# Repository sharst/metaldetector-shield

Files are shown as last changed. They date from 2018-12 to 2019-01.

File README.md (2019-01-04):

# metaldetector-shield
Hardware and Software for a custom built metaldetector + pressure sensing shield.
This shield was used in a robotics project for contactless navigation (see https://www.youtube.com/watch?v=rSrG_VnvrPk). 
The hardware and software were jointly developed by Simon Harst and Stefan Brüwer.

## It features:
* connection of up to 8 coils which emit and receive electromagnetical impulses
* connection of up to 8 pressure sensors to detect air pulses
* 24V connection with on-board conversion to 5V for the microcontroller
* on-board CAN-Controller to connect the board to a CAN-bus
* chaining possibility to connect two or more boards together for infinite extension
* a ROS example to use it in your robotics application: [www.github.com/sharst/metaldetector-ros](https://github.com/sharst/metaldetector-ros)

## What you can do with it:
* Contactlessly detect metal objects in the vicinity (distance depends on the coil and object used)
* build a rig of 8, 16 or more coils by chaining several boards together
* detect changes in air pressure (in our case upon collision inside an inflateable bumper)
* send all the information on a CAN or serial bus

The board and all accompanying software is fully open source, so you can get involved, too!

## Hardware setup
### How does this work?
The heart of this shield is an arduino microcontroller, which rapidly triggers 8 rigs of transistors connected to coils. From the impulse of current, the coils generate an electromagnetical impulse. In case there is metal in front of the coil, it will reflect part of the impulse which in turn can be sensed by the coil. The weaker echo of the impulse is again converted to current in the coil, which is measured by an ADC on the board. If you want to see a typical response as measured by the ADC, check out the coil response gif below (--> Configuration files). The board sums up the response. This sum can be used to infer whether a metal object is present and how far away it is.

In addition, the shield can measure impact in terms of air pressure. To do that it constantly measures a rolling average of up to 8 air pressure sensors independently. In case it measures a spike of air pressure above a threshold, it emits a custom message.

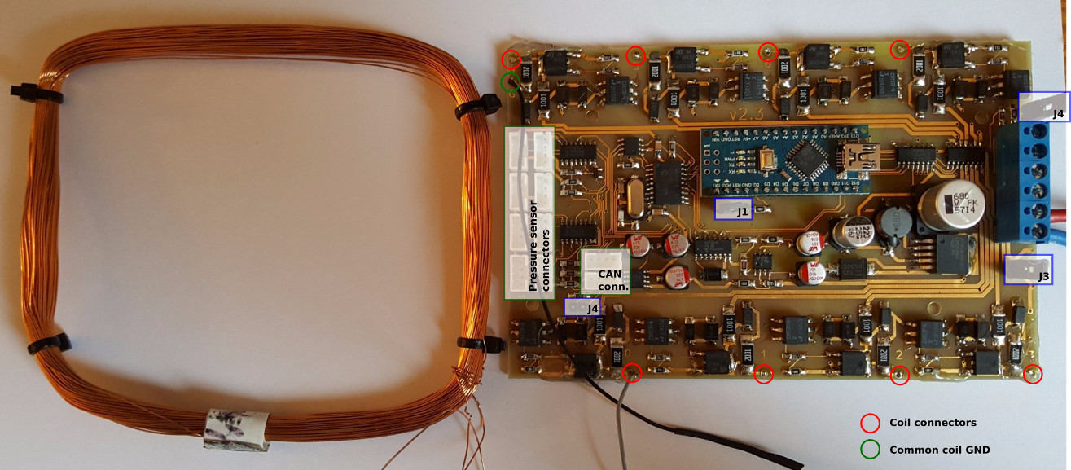
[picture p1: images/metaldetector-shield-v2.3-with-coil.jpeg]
The metaldetector shield


This is what needs to be done to get one board running (no chaining):
* Solder at least one sensing coil to the COIL_GND and COIL_0 inputs (for more information, check out --> "A note on the coils"
* (Optionally) connect one BMP180-pressure sensor to one of the pressure inputs
* Connect the arduino on the board to your PC and flash the current firmware
* Set jumper J1 to set the board to MASTER mode
* Set jumper J2 to disable chaining
* In case you do not have a coil/capacitor installed at the 24V input, set jumper J3 to bridge the coil connector
* Connect 24V to one of the 24V ports
* The values of the coils are being output on the serial port now (115200baud)

### To enable chaining
Chaining allows you to connect two boards together. The impulses of the coils will influence one another. Therefore you should not operate two coils close together if you want accurate results. The metaldetector board already takes care that up to 8 coils are fired independently in a row and do not influence each other. If you need more than 8 coils, you can use chaining. Chaining uses an additional signal line between two boards, and the boards will take care to always fire their coils alternatingly.
* Remove jumper J2 to enable chaining
* Set jumper J1 on one board to make it the chaining MASTER. Remove the jumper on all other boards to make them slaves
* You can directly chain the 24V power source as well by connecting the secondary 24V-port to the next board
* Connect to signal wires between the boards. The first one should go from output (>) on board 1 to input (<) on board 2. The second one goes from input (<) on board 1 to output (>) on board 2.
* If you want to connect more than two boards together, connect them in a circle, always taking care that the output goes to the input of the next board, and the input is connected to the output of the previous board.
* If you are using the CAN bus, make sure that the boards are using unique CAN addresses (set them in metaldetector-shield.ino --> TX_CAN_ID and RX_CAN_ID)

### How to produce the boards
* We always ordered our boards at PCB-Pool (in Germany). They accept the kicad-files given in the hardware folder directly as input. 
* You can order the entire BOM on farnell, including the wire for the coils. Check out the BOM in the hardware folder.

### A word on the coils
The coils are key when it comes to which objects can be detected. Here's a few notes:
* The larger the coil diameter, the less focused the impulse will be. In general you get a weaker response with larger coils, but also you cover less area
* We tested both with round and rectangular coils, both worked great.
* The more impedance, the less current flow you will get at the fixed 24V, which means less stronger impulses and responses. But it also means less power consumption.
* The more windings the coil has, the stronger the impulse. But also you will naturally get higher impedance with more windings.
* you will have to experiment to find the best tradeoff for your application. In our case it was a coil from 0.4mm wire with 150 windings equalling to ~11 Ohm.

### A note on the pressure sensors
* We ordered the BMP180 sensors on ebay. Note that there are several versions. The boards we used are 1cm x 1.2cm in size. We hand-crimped the cables to connect them via the JST-plugs.
* If you want to use pressure sensors in an outdoor environment, water resistance is key. We used two cable glands connected together to create an air- and water-tight case. We connected an air tube from the one side which guided the air impulse from the bumper cushion into the case (blue arrow). On the other end we connected the air pressure sensor (red arrow). [See image here.](https://github.com/sharst/metaldetector-shield/blob/master/images/air_pressure_connector.jpg).
* For extra water resistance, it is possible to put the pressure sensor into a ballon before inserting it into the cable gland. [See image here.](https://github.com/sharst/metaldetector-shield/blob/master/images/air_pressure_connector_balloon.jpeg)

## Software setup
We've tried to make the software setup as easy as possible for you. Therefore, all the software needed is bundled in this repository, either directly or by submodules.

### To get the arduino running
```
# Go anywhere where you want to check out this repo
cd ~
git clone https://github.com/sharst/metaldetector-shield
cd metaldetector-shield
# Get all the contained submodules
git submodule init 
git submodule update
# The repository contains an arduino folder. This is basically an arduino sketchbook setup and ready to go. First backup your current one:
mv ~/sketchbook ~/sketchbook_bckp
# Now link the one from the repository with a symbolic link. This means you can still use and manage the repository in the original location, but arduino will find your files.
ln -s ~/metaldetector-shield/arduino ~/sketchbook
```
* Open the arduino IDE (tested with v 1.6.9)
* Select Tools --> Board --> Arduino Nano
* Tools --> Programmer --> AVR ISP
* File --> Open --> ~/sketchbook/arduino/metaldetector_shield.ino
* Upload
* Open Serial Console, set it to 115200 baud, watch the output.

### Overview of the software
./arduino: Contains all the software relevant to the arduino (i.e. the firmware and all libraries)
./PythonLivePlotting: A library to do dynamical plots and updates of figures

#### Configuration files
board_v23.h : Contains mostly pin settings (hardwired on the board, don't change them!). You can also set some identifiers on where pressure and heartbeat signals get send on the CAN-BUS, and the identifier to switch coils.  
metaldetector-shield.ino: The main sketch for upload. Contains some interesting settings:
  * TX_CAN_ID: The CAN ID used for writing messages on the bus. If you are using several boards on the same bus, make sure this is unique for each board.
  * RX_CAN_ID: The ID that this board listens on for messages on the bus. You can dynamically switch some functionalities on the board by sending messages. Make sure this ID is unique for this board.
  * DEBUG: Whether or not to output information on the serial bus.
  * COMM_TIMEOUT: How many ms to wait for a signal from the slave board in chaining mode
  * DEBUG_RAW_ADC_COIL: Only works when DEBUG==true. This will output the raw measurements of the given coil as sampled by the ADC. Run python plot_raw_coil.py to visualize these values. This is a sample output where we approach a metal object to the coil:
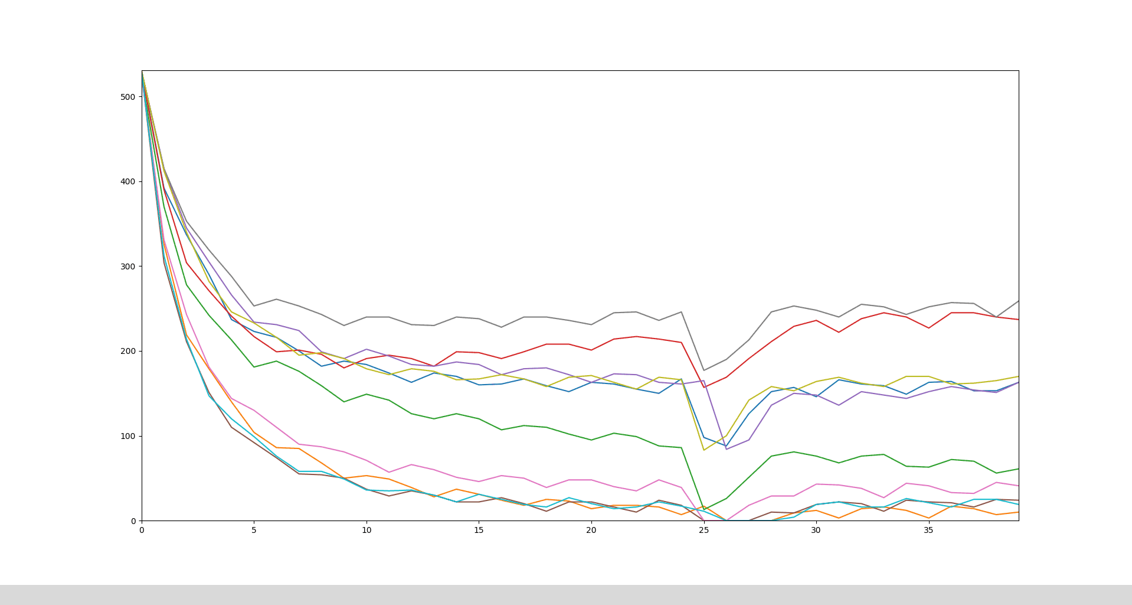
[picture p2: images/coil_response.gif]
Raw output of ADC values

  * DEBUG_RAW_PRESSURE: Only works when DEBUG==true. This will output the raw measurements of the given pressure sensor. Run python plot_raw_pressure.py to visualize these values. This is a sample output where we register several bumper hits on the given pressure sensor. In red are detected collisions.
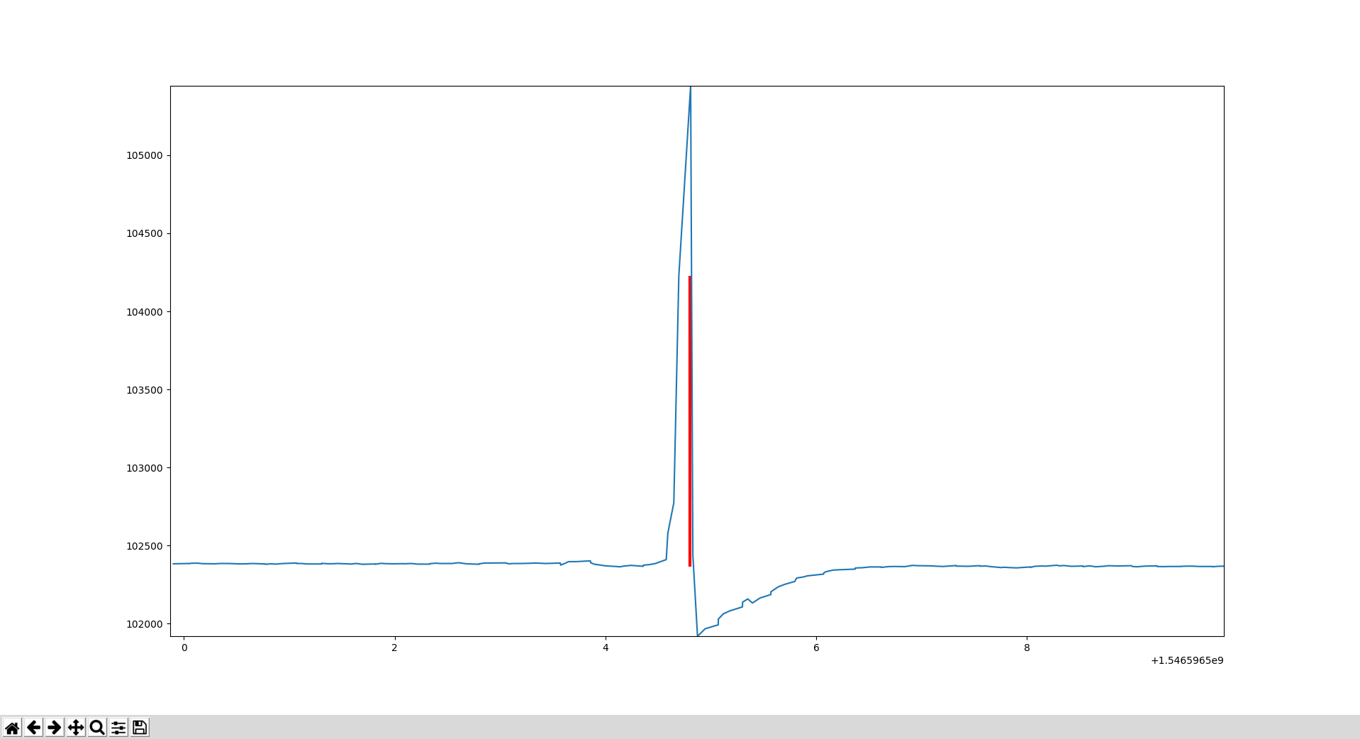
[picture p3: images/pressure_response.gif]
Raw output of pressure values
  

#### Typical operation mode
Check out the loop-function in the main sketch. A loop consists of the following steps:
* If coils are enabled, trigger each coil once and read out the results
* we want to average over several measurements. coil.data_ready() goes to True as soon as we have collected this amount of measurements
* In case some coil data is ready we will output it on the serial bus as a four-byte message, which will be in the format ```[40 (COIL_REGISTER set in board_v23.h), [0-7] (coil_index), highbyte(value), lowbyte(value)]```
* The communication state is toggled so the next board can start measuring
* We now sample the pressure sensors. If one of them transitions a threshold value, we encode this information bitwise. For instance, if pressure sensors 2 and 4 have surpassed the threshold value since the last call, get_bumper_transitions will output 0b00010100 (the second and fourth bit are True).
* We now send out the string "BUMPER" on the serial bus. On the CAN-bus we will send the bitcoded value, this time in the format ```[25 (PRESSURE_REGISTER set in board_v23.h), 0, highbyte(bitcode), lowbyte(bitcode)]```.
* We send out a heartbeat message on the CAN bus. This message contains the information on which ports some pressure sensors are connected and whether the metal sensing functionality is currently switched on. Which ports are currently connected to pressure sensors is again encoded bitwise, i.e. 0b10001001 means that there are sensors connected on the first, fourth and eigth connector on the board. A heartbeat message has the format ```[30 (HEARTBEAT_REGISTER set in board_v23.h), bitwise encoding of connected sensors, (1 or 0 whether coils are enabled)]```

#### Getting the CAN bus running
* In order to interface with a CAN bus from a computer, you typically need a CAN to USB converter. We had some eccellent results with the [USBtin](https://www.fischl.de/usbtin/). It is open source, has a superb interface, a loving maintainer and can be ordered readily assembled.
* In order to connect it, just connect the HIGH, LOW and GND (marked as "T" on the USBtin) lines between the two boards. 
* If you want to connect more metaldetector boards, there are two CAN connectors on each one: One coming in, one going out.
* In addition, you need one termination resistor somewhere on the bus, typically on the last element of the bus chain. If this last element is a metaldetector board, you can simply set jumper J4 to enable the termination resistor.
* Connect the USBTin to your computer, open the interface and set it to 500kbps and see the messages from the board coming in. 
* There is also a ROS driver available which directly interfaces the metaldetector-board to ROS messages [www.github.com/sharst/metaldetector-ros](www.github.com/sharst/metaldetector-ros)

## Summary: Information flow from the metaldetector-shield
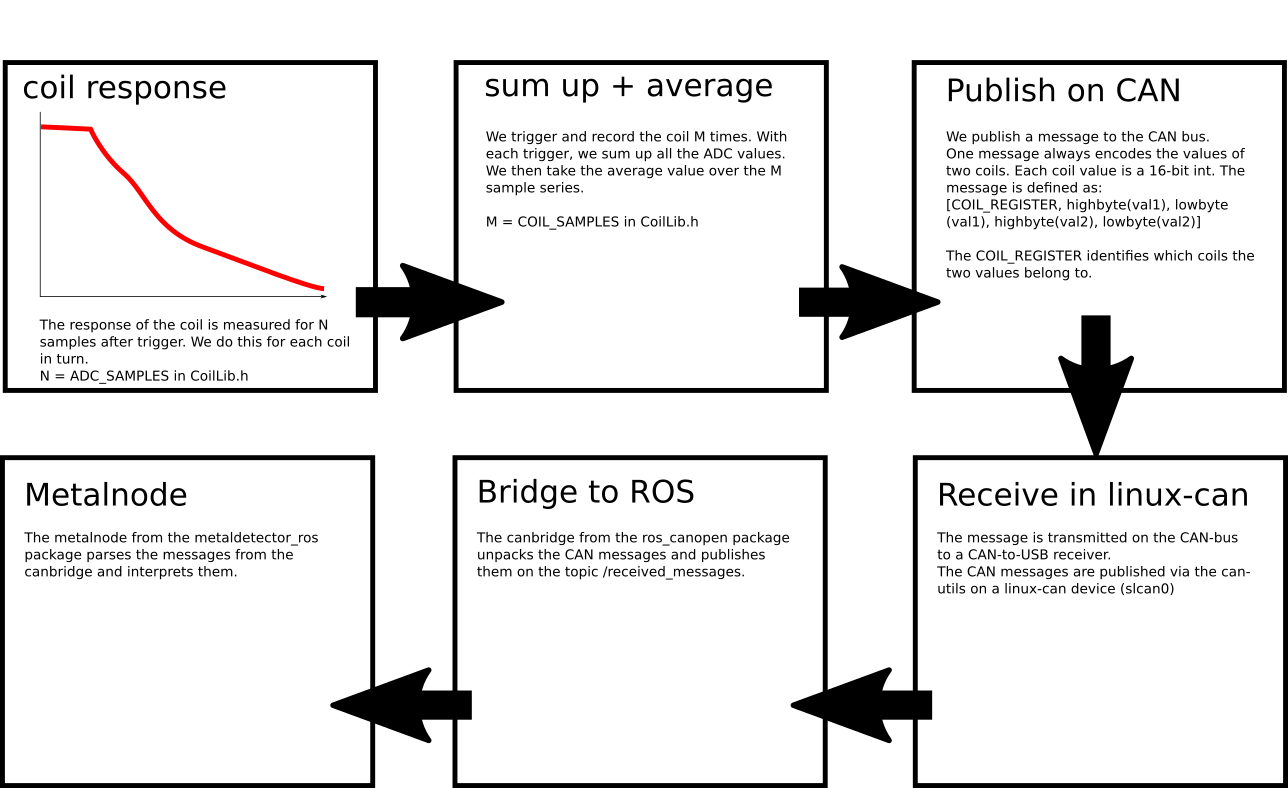
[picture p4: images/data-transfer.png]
Information flow from the metaldetector-shield


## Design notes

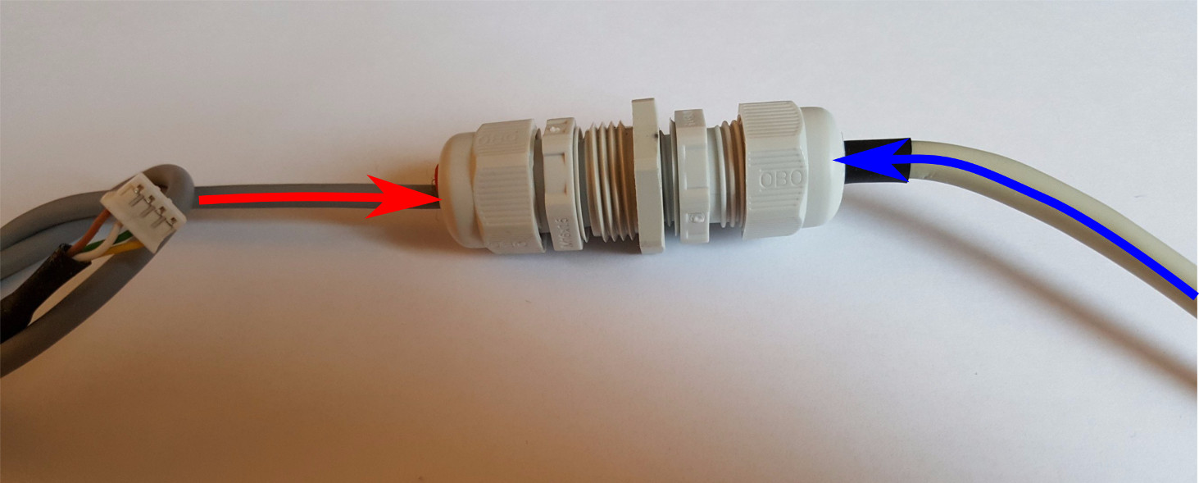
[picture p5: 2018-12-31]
images/air_pressure_connector.jpg

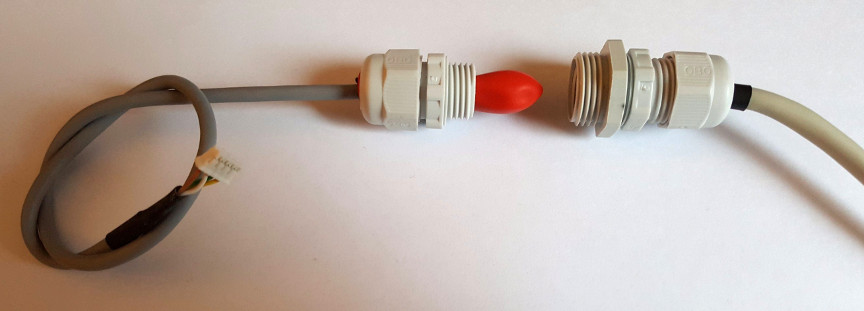
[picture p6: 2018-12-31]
images/air_pressure_connector_balloon.jpeg

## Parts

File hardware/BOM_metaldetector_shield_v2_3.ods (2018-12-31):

BOM Metaldetector Shield v2.3
 |  | SMD
Name | Value | Quantity | Farnell # | Price | Total Price
AMP1 | LF356N | 1 | 9486992 | 0.74 | 0.74
C1, C11, C12 | 47uF | 3 | 2466299 | 0.237 | 0.711
C2 | 16MHz | 1 | 1667017 | 0.357 | 0.357
C3, C4 | 27pF | 2 | 1650899 | 0.109 | 0.218
C5, C6 | 100nF | 2 | 1856626RL | 0.0158 | 0.0316
C7 | 680uF / 50V | 1 | 2326375 | 1.55 | 1.55
C8, C9 | 100uF | 2 | 2466283 | 0.138 | 0.276
C10 | 220uF / 25V | 1 | 2068666 | 0.353 | 0.353 | alternativ 100uF: 1135108
D1, D6, D9, D12, D15, D18, D21, D24, D27, D30, D33 | Schottky 1A / 20V | 9 | 1861424 | 0.0777 | 0.6993
D3 | 1n5824 | 1 | 1843766 | 1.09 | 1.09
D4, D7, D10, D13, D16, D19, D22, D25, D28, D31 | TVS 400V | 8 | 1835131 | 0.673 | 5.384
D5, D8, D11, D14, D17, D20, D23, D26, D29, D32 | TVS 5V | 8 | 1899459 | 0.348 | 2.784
IC1 | 74HC4052 | 2 | 1201328 | 0.361 | 0.722
IC2 | MCP2515 | 1 | 1292239 | 1.86 | 1.86
IC3 | MCP2551 | 1 | 9758569 | 1.06 | 1.06
L1 | 68uH | 1 | 1828056 | 0.414 | 0.414 | alternativ 100uH: 2329044
MCP1 | MCP3008 | 1 | 1292241 | 2.25 | 2.25
P5 | 220 Ohm | 1 | 2447486RL | 0.0042 | 0.0042
Q1-Q10 | Mosfet | 8 | 2344093 | 3.55 | 28.4
R1, R2, R3, R9 | 10k | 4 | 2073878 | 0.0116 | 0.0464
R4, R7, R8 | 100 Ohm | 1 | 1632521 | 0.006 | 0.006
R5 | 560 Ohm | 3 | 1632593 | 0.006 | 0.018
R6 | 560k | 1 | 2145676 | 0.01 | 0.01
R10 | 350 Ohm | 1 | 2142160 | 0.024 | 0.024
R11, R15, R19, R23, R27, R31, R35, R39, R43, R47 | 2k Planar | 8 | 1887796 | 0.857 | 6.856
R12, R16, R20, R24, R28, R32, R36, R40, R44, R48 | 1k / 1W | 8 | 1470042 | 0.16 | 1.28
r14, r18, r22, r26, r30, r34, r38, r42, r46, r50 | 220 Ohm | 8 | 2447486RL | 0.0042 | 0.0336
U1 | ICL7660 | 1 | 9663703 | 1.1 | 1.1
U2 | LM2596-T5.0 | 1 | 1469195 | 4.54 | 4.54
U3, U4, U5, U6 | HEF4051 | 4 | 1201291 | 0.254 | 1.016
U7-U16 | CNY17F OPTO | 8 | 1683186 | 0.57 | 4.56
Arduino Nano | NANO | 1 |  |  | 0
P5, P19, P18 |  | 3 | 2007995 | 0.313 | 0.939
JP1, JP2, JP3, JP4 | 2Pin-Header | 2 | 1248140 | 0.054 | 0.108
JP1, JP2, JP3, JP4 | Jumper 2Pos | 2 | 1908384 | 0.073 | 0.146
J2, P25, P2, P3, P4, P6, P7, P8, P9, P10 | JSP PH 4Pos | 10 | 9492437 | 0.144 | 1.44
R28, R51 | 1k | 10 | DNO | 0 | 0
P5, P18, P19 | Reihenklemmen RM5 | 3 | 2396252 | 0.243 | 0.729
Optional: |  |  |  |  | 67.6541
-- | Drossel |  | 1929754 | 2.9
-- | ELKO 4700uF |  | 1973498 | 2.96
 | Flachsteckeranschluss |  | Reichelt FS-P 2,8

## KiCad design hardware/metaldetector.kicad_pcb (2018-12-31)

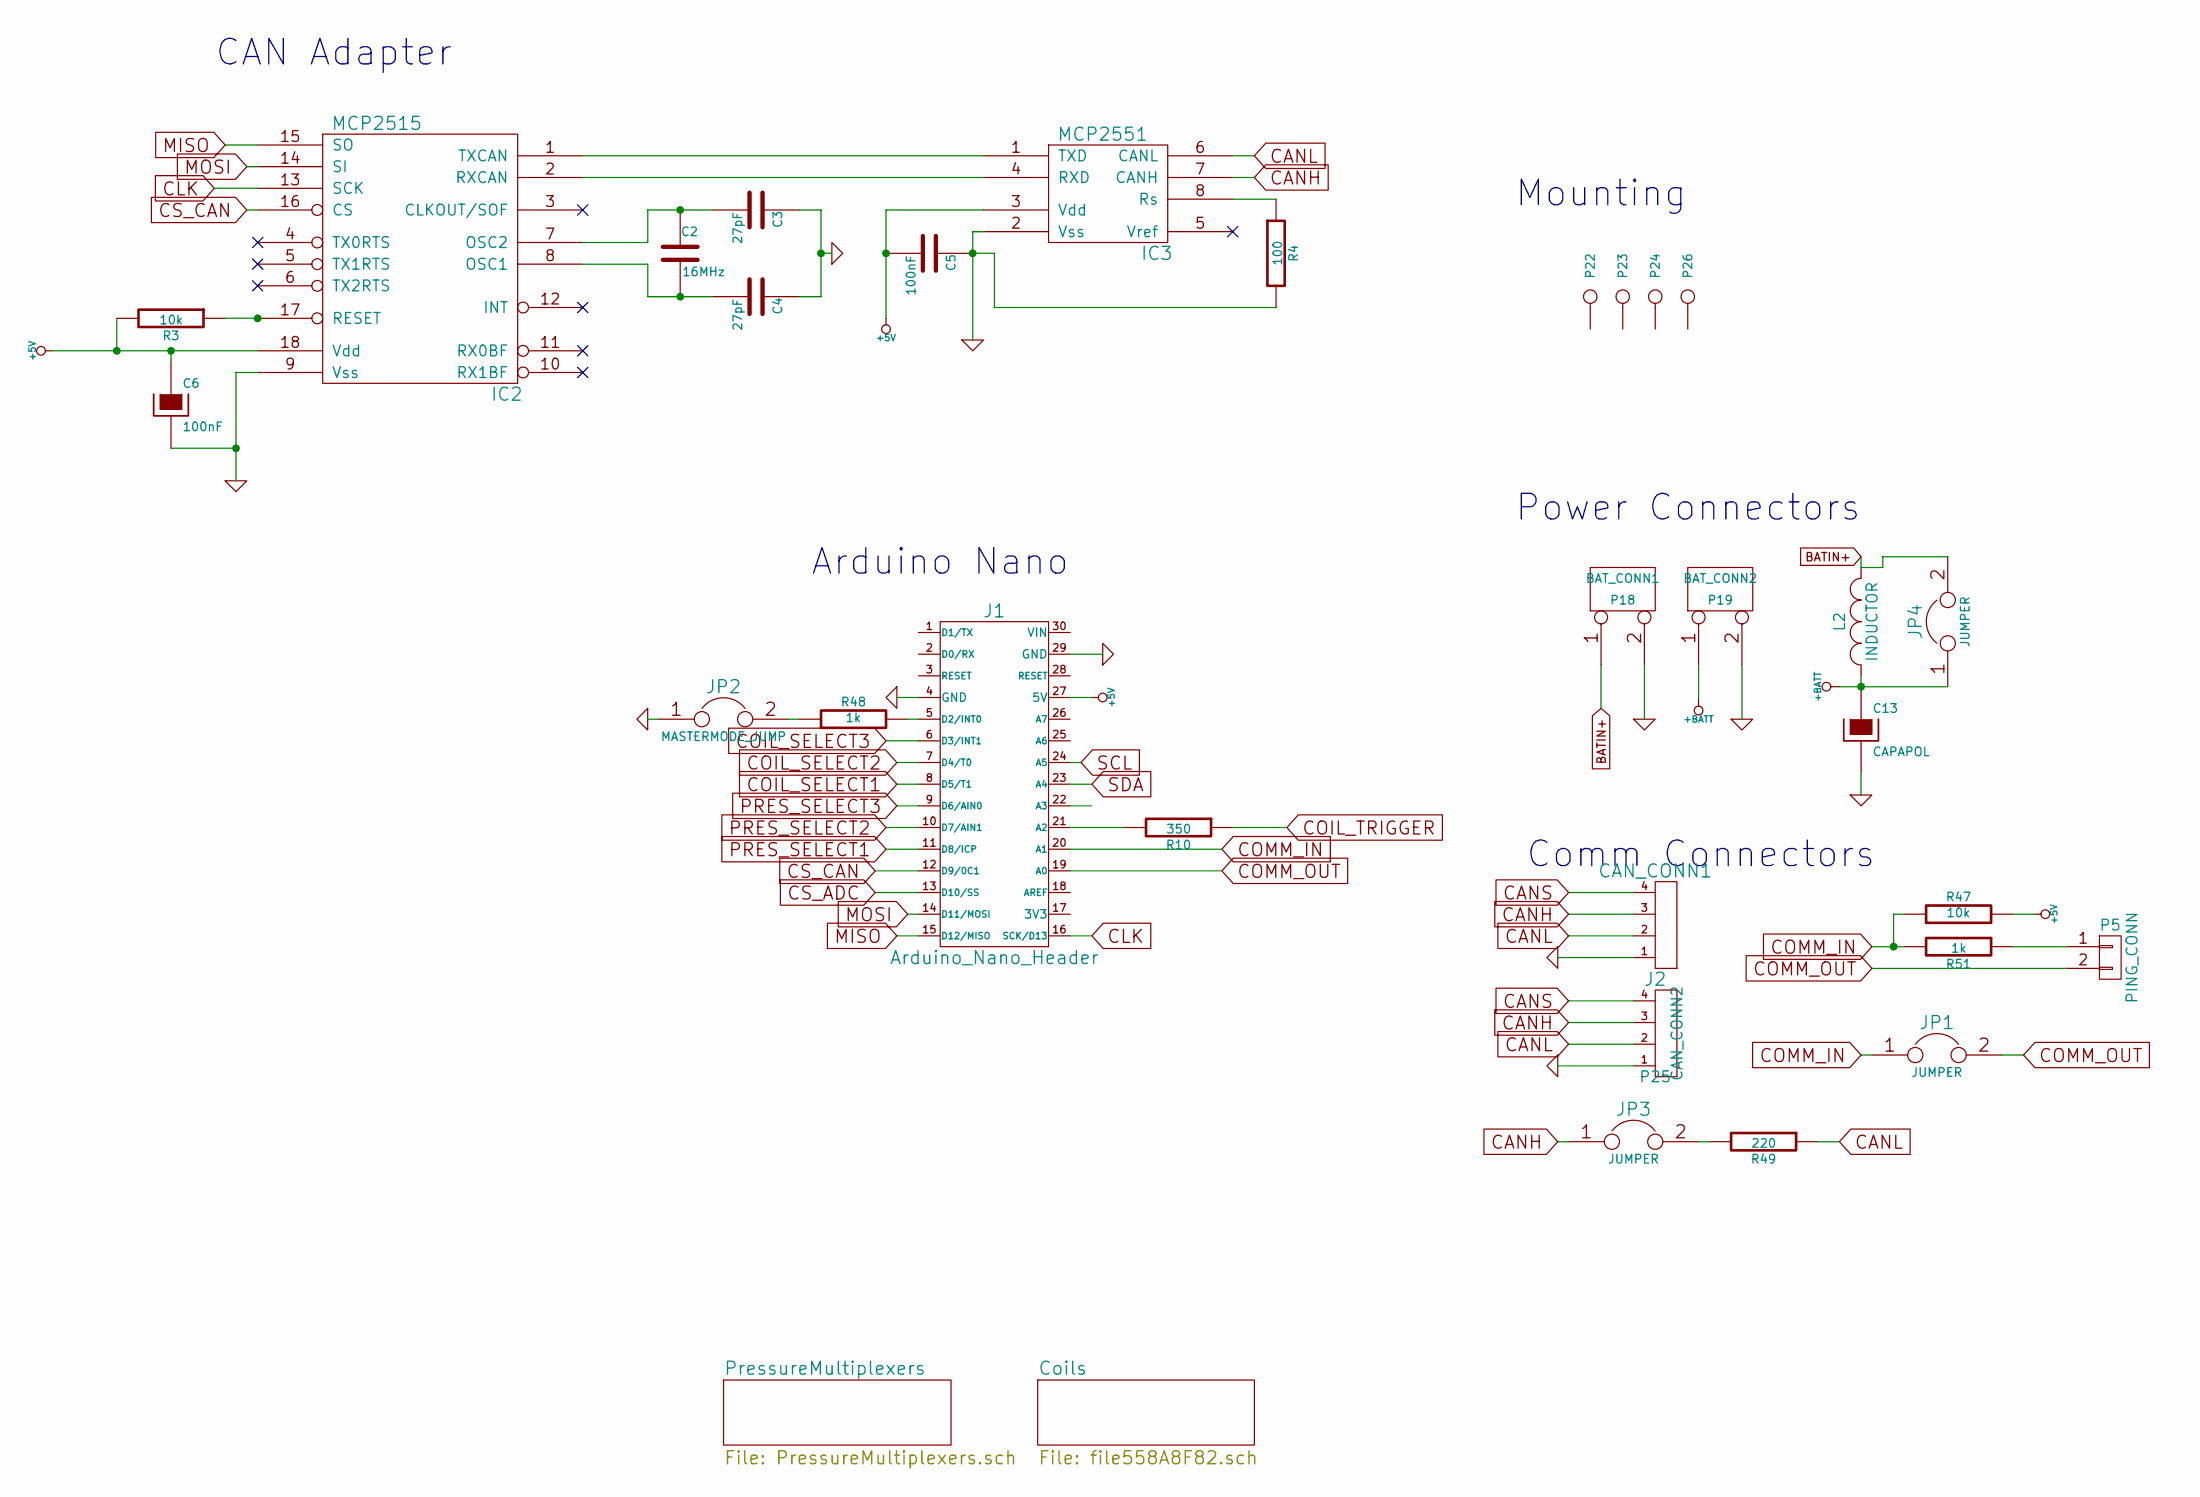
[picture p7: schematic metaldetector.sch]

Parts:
C2: 16MHz; HC49SM-Crystal16MHz
C3, C4: 27pF; C_1206_HandSoldering
C5, C6: 100nF; C_1206_HandSoldering
C13: CAPAPOL; C_Radial_D18_L36_P7.5
IC2: MCP2515; SOIC-18_7.5x11.6mm_Pitch1.27mm
IC3: MCP2551; SOIC-8_3.9x4.9mm_Pitch1.27mm
J1: Arduino_Nano_Header; arduino_nano_header
J2: CAN_CONN1; b4b-ph-kl
JP1, JP3, JP4: JUMPER; Socket_Strip_Straight_1x02
JP2: MASTERMODE_JUMP; Socket_Strip_Straight_1x02
L2: INDUCTOR; BOURNS-2324-V-RC
P5: PING_CONN; mkds_1,5-2
P18: BAT_CONN1; mkds_1,5-2
P19: BAT_CONN2; mkds_1,5-2
P22, P23, P24, P26: CONN_1; bore
P25: CAN_CONN2; b4b-ph-kl
R3, R47: 10k; R_1206_HandSoldering
R4: 100; R_1206_HandSoldering
R10: 350; R_1206_HandSoldering
R48, R51: 1k; R_1206_HandSoldering
R49: 220; R_1206_HandSoldering

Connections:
+5V: C5.2, C6.1, IC2.18 (Vdd), IC3.3 (Vdd), J1.27 (5V), R3.2, R47.2; also elsewhere on the board
+BATT: C13.1, JP4.1, L2.1, P19.1; also elsewhere on the board
BATIN+: JP4.2, L2.2, P18.1
CANH: IC3.7 (CANH), J2.3, JP3.1, P25.3
CANL: IC3.6 (CANL), J2.2, P25.2, R49.1
CANS: J2.4, P25.4
CLK: IC2.13 (SCK), J1.16 (SCK/D13); also elsewhere on the board
COIL_SELECT1: J1.8 (D5/T1); also elsewhere on the board
COIL_SELECT2: J1.7 (D4/T0); also elsewhere on the board
COIL_SELECT3: J1.6 (D3/INT1); also elsewhere on the board
COIL_TRIGGER: R10.1; also elsewhere on the board
COMM_IN: J1.20 (A1), JP1.1, R47.1, R51.2
COMM_OUT: J1.19 (A0), JP1.2, P5.2
CS_ADC: J1.13 (D10/SS); also elsewhere on the board
CS_CAN: IC2.16 (CS), J1.12 (D9/0C1)
GND: C3.1, C4.1, C5.1, C6.2, C13.2, IC2.9 (Vss), IC3.2 (Vss), J1.4 (GND), J1.29 (GND), J2.1, JP2.1, P18.2 (PM), P19.2 (PM), P25.1, R4.2; also elsewhere on the board
MISO: IC2.15 (SO), J1.15 (D12/MISO); also elsewhere on the board
MOSI: IC2.14 (SI), J1.14 (D11/MOSI); also elsewhere on the board
unnamed: C2.1, C3.2, IC2.7 (OSC2)
unnamed: C2.2, C4.2, IC2.8 (OSC1)
unnamed: IC2.1 (TXCAN), IC3.1 (TXD)
unnamed: IC2.2 (RXCAN), IC3.4 (RXD)
unnamed: IC2.17 (RESET), R3.1
unnamed: IC3.8 (Rs), R4.1
unnamed: J1.5 (D2/INT0), R48.2
unnamed: J1.21 (A2), R10.2
unnamed: JP2.2, R48.1
unnamed: JP3.2, R49.2
unnamed: P5.1, R51.1
PRES_SELECT1: J1.11 (D8/ICP); also elsewhere on the board
PRES_SELECT2: J1.10 (D7/AIN1); also elsewhere on the board
PRES_SELECT3: J1.9 (D6/AIN0); also elsewhere on the board
SCL: J1.24 (A5); also elsewhere on the board
SDA: J1.23 (A4); also elsewhere on the board

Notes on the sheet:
CAN Adapter
Arduino Nano
Power Connectors
Comm Connectors
Mounting

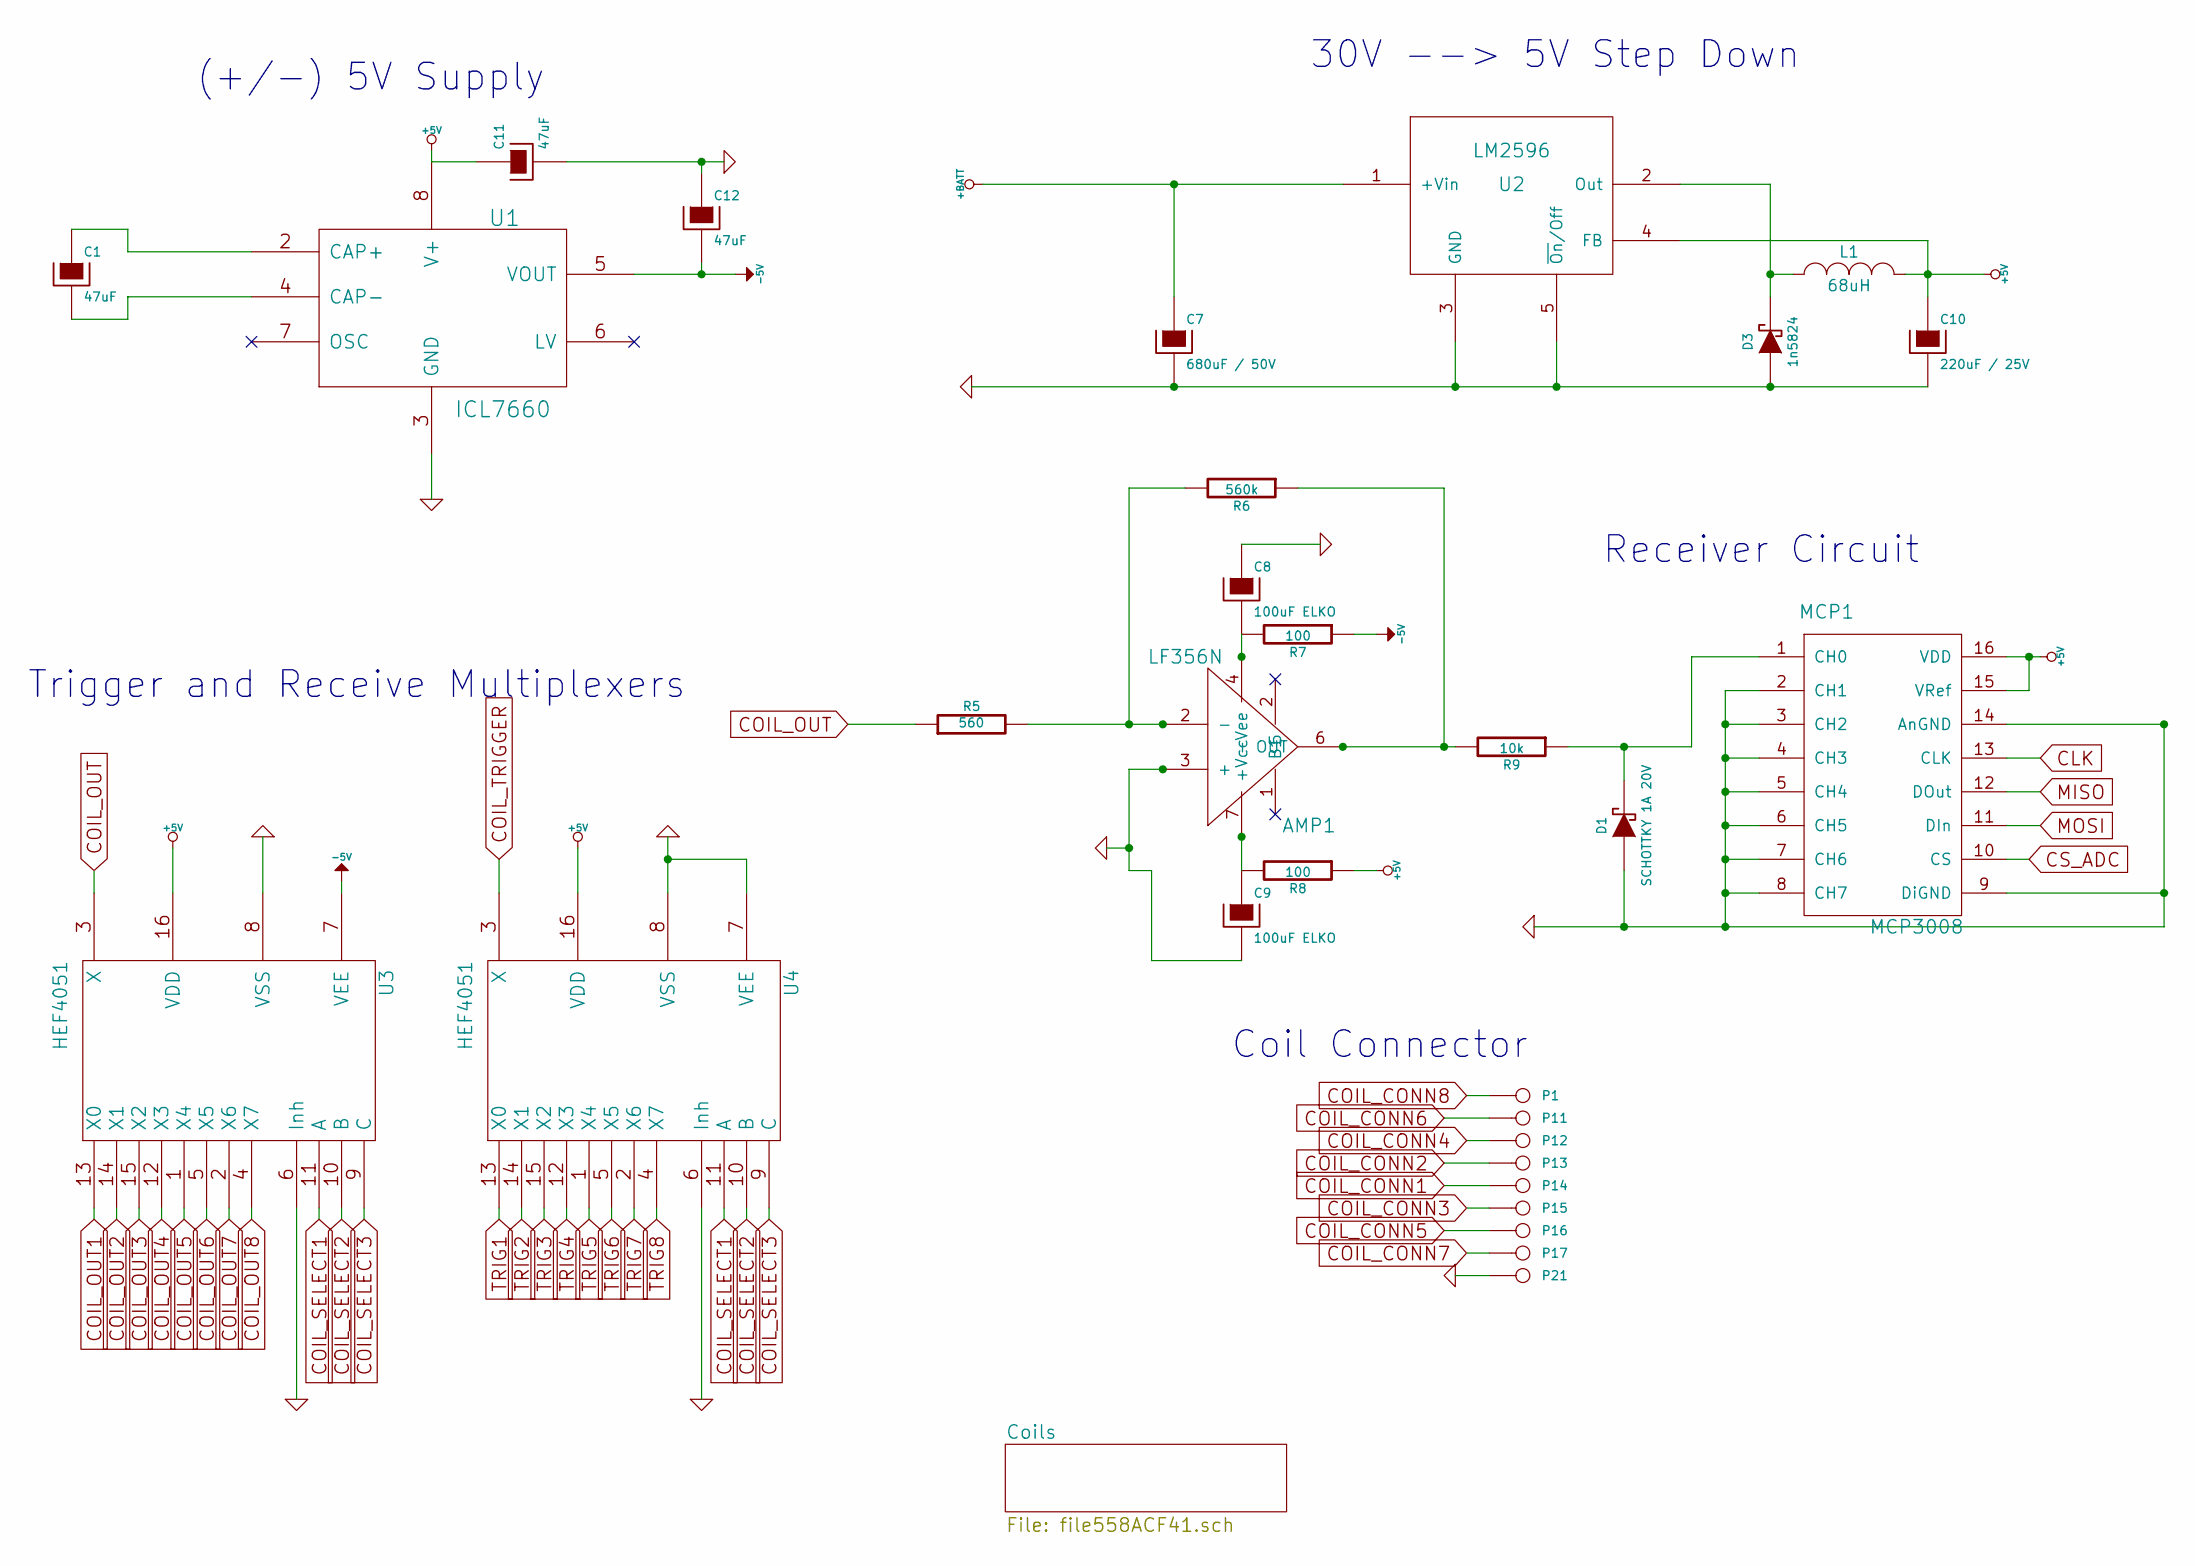
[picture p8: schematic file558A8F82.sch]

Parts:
AMP1: LF356N; SOIC-8_3.9x4.9mm_Pitch1.27mm
C1, C11, C12: 47uF; c_elec_6.3x5.3
C7: 680uF / 50V; CAP_D12_5_H13_5_SMD
C8, C9: 100uF ELKO; c_elec_6.3x5.3
C10: 220uF / 25V; c_elec_8x10.5
D1: SCHOTTKY 1A 20V; DO-214AC_Handsoldering
D3: 1n5824; DO-214AB_Handsoldering
L1: 68uH; Ind_68uH
MCP1: MCP3008; SOIC-16_3.9x9.9mm_Pitch1.27mm
P1, P11, P12, P13, P14, P15, P16, P17, P21: CONN_1; solderpad_single
R5: 560; R_1206_HandSoldering
R6: 560k; R_1206_HandSoldering
R7, R8: 100; R_1206_HandSoldering
R9: 10k; R_1206_HandSoldering
U1: ICL7660; SOIC-8_3.9x4.9mm_Pitch1.27mm
U2: LM2596; TO-263-5
U3, U4: HEF4051; SOIC-16_3.9x9.9mm_Pitch1.27mm

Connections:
+5V: C10.1, C11.1, L1.2, MCP1.15 (VRef), MCP1.16 (VDD), R8.1, U1.8 (V+), U2.4 (FB), U3.16 (VDD), U4.16 (VDD); also elsewhere on the board
+BATT: C7.1, U2.1 (+Vin); also elsewhere on the board
-5V: C12.2, R7.1, U1.5 (VOUT), U3.7 (VEE)
CLK: MCP1.13 (CLK); also elsewhere on the board
COIL_CONN1: P14.1; also elsewhere on the board
COIL_CONN2: P13.1; also elsewhere on the board
COIL_CONN3: P15.1; also elsewhere on the board
COIL_CONN4: P12.1; also elsewhere on the board
COIL_CONN5: P16.1; also elsewhere on the board
COIL_CONN6: P11.1; also elsewhere on the board
COIL_CONN7: P17.1; also elsewhere on the board
COIL_CONN8: P1.1; also elsewhere on the board
COIL_OUT: R5.1, U3.3 (X)
COIL_OUT1: U3.13 (X0); also elsewhere on the board
COIL_OUT2: U3.14 (X1); also elsewhere on the board
COIL_OUT3: U3.15 (X2); also elsewhere on the board
COIL_OUT4: U3.12 (X3); also elsewhere on the board
COIL_OUT5: U3.1 (X4); also elsewhere on the board
COIL_OUT6: U3.5 (X5); also elsewhere on the board
COIL_OUT7: U3.2 (X6); also elsewhere on the board
COIL_OUT8: U3.4 (X7); also elsewhere on the board
COIL_SELECT1: U3.11 (A), U4.11 (A); also elsewhere on the board
COIL_SELECT2: U3.10 (B), U4.10 (B); also elsewhere on the board
COIL_SELECT3: U3.9 (C), U4.9 (C); also elsewhere on the board
COIL_TRIGGER: U4.3 (X); also elsewhere on the board
CS_ADC: MCP1.10 (CS); also elsewhere on the board
GND: AMP1.3 (+), C7.2, C8.1, C9.2, C10.2, C11.2, C12.1, D1.1 (A), D3.1 (A), MCP1.2 (CH1), MCP1.3 (CH2), MCP1.4 (CH3), MCP1.5 (CH4), MCP1.6 (CH5), MCP1.7 (CH6), MCP1.8 (CH7), MCP1.9 (DiGND), MCP1.14 (AnGND), P21.1, U1.3 (GND), U2.3 (GND), U2.5 (~On~/Off), U3.6 (Inh), U3.8 (VSS), U4.6 (Inh), U4.7 (VEE), U4.8 (VSS); also elsewhere on the board
MISO: MCP1.12 (DOut); also elsewhere on the board
MOSI: MCP1.11 (DIn); also elsewhere on the board
unnamed: AMP1.2 (-), R5.2, R6.2
unnamed: AMP1.4 (-Vee), C8.2, R7.2
unnamed: AMP1.6 (OUT), R6.1, R9.2
unnamed: AMP1.7 (+Vcc), C9.1, R8.2
unnamed: C1.1, U1.2 (CAP+)
unnamed: C1.2, U1.4 (CAP-)
unnamed: D1.2 (K), MCP1.1 (CH0), R9.1
unnamed: D3.2 (K), L1.1, U2.2 (Out)
TRIG1: U4.13 (X0); also elsewhere on the board
TRIG2: U4.14 (X1); also elsewhere on the board
TRIG3: U4.15 (X2); also elsewhere on the board
TRIG4: U4.12 (X3); also elsewhere on the board
TRIG5: U4.1 (X4); also elsewhere on the board
TRIG6: U4.5 (X5); also elsewhere on the board
TRIG7: U4.2 (X6); also elsewhere on the board
TRIG8: U4.4 (X7); also elsewhere on the board

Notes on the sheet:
30V --> 5V Step Down
(+/-) 5V Supply
Receiver Circuit
Coil Connector
Trigger and Receive Multiplexers

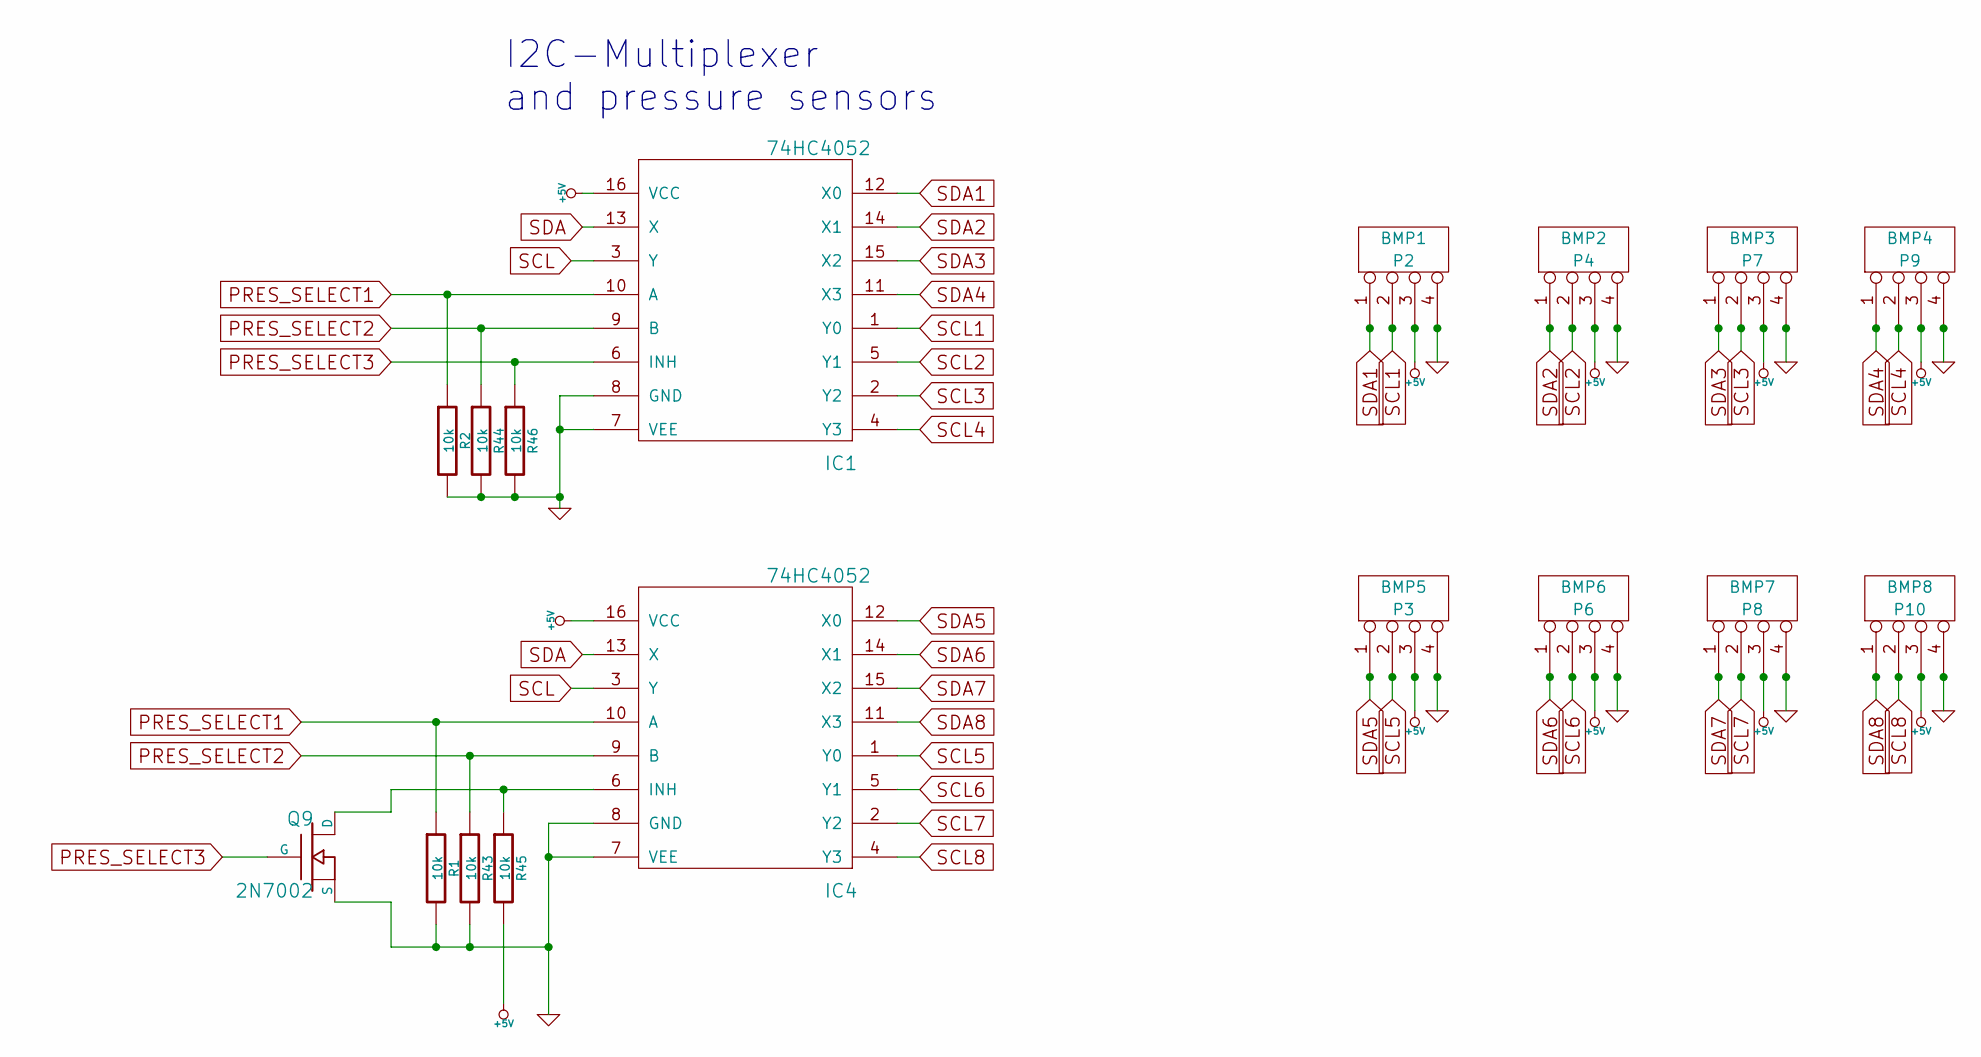
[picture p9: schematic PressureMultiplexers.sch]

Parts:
IC1, IC4: 74HC4052; SOIC-16_3.9x9.9mm_Pitch1.27mm
P2: BMP1; b4b-ph-kl
P3: BMP5; b4b-ph-kl
P4: BMP2; b4b-ph-kl
P6: BMP6; b4b-ph-kl
P7: BMP3; b4b-ph-kl
P8: BMP7; b4b-ph-kl
P9: BMP4; b4b-ph-kl
P10: BMP8; b4b-ph-kl
Q9: 2N7002; SOT-23_Handsoldering-MOS-N
R1, R2, R43, R44, R45, R46: 10k; R_1206_HandSoldering

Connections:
+5V: IC1.16 (VCC), IC4.16 (VCC), P2.3, P3.3, P4.3, P6.3, P7.3, P8.3, P9.3, P10.3, R45.2; also elsewhere on the board
GND: IC1.7 (VEE), IC1.8 (GND), IC4.7 (VEE), IC4.8 (GND), P2.4, P3.4, P4.4, P6.4, P7.4, P8.4, P9.4, P10.4, Q9.S, R1.2, R2.2, R43.2, R44.2, R46.2; also elsewhere on the board
unnamed: IC4.6 (INH), Q9.D, R45.1
PRES_SELECT1: IC1.10 (A), IC4.10 (A), R1.1, R2.1; also elsewhere on the board
PRES_SELECT2: IC1.9 (B), IC4.9 (B), R43.1, R44.1; also elsewhere on the board
PRES_SELECT3: IC1.6 (INH), Q9.G, R46.1; also elsewhere on the board
SCL: IC1.3 (Y), IC4.3 (Y); also elsewhere on the board
SCL1: IC1.1 (Y0), P2.2
SCL2: IC1.5 (Y1), P4.2
SCL3: IC1.2 (Y2), P7.2
SCL4: IC1.4 (Y3), P9.2
SCL5: IC4.1 (Y0), P3.2
SCL6: IC4.5 (Y1), P6.2
SCL7: IC4.2 (Y2), P8.2
SCL8: IC4.4 (Y3), P10.2
SDA: IC1.13 (X), IC4.13 (X); also elsewhere on the board
SDA1: IC1.12 (X0), P2.1
SDA2: IC1.14 (X1), P4.1
SDA3: IC1.15 (X2), P7.1
SDA4: IC1.11 (X3), P9.1
SDA5: IC4.12 (X0), P3.1
SDA6: IC4.14 (X1), P6.1
SDA7: IC4.15 (X2), P8.1
SDA8: IC4.11 (X3), P10.1

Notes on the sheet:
I2C-Multiplexer and pressure sensors

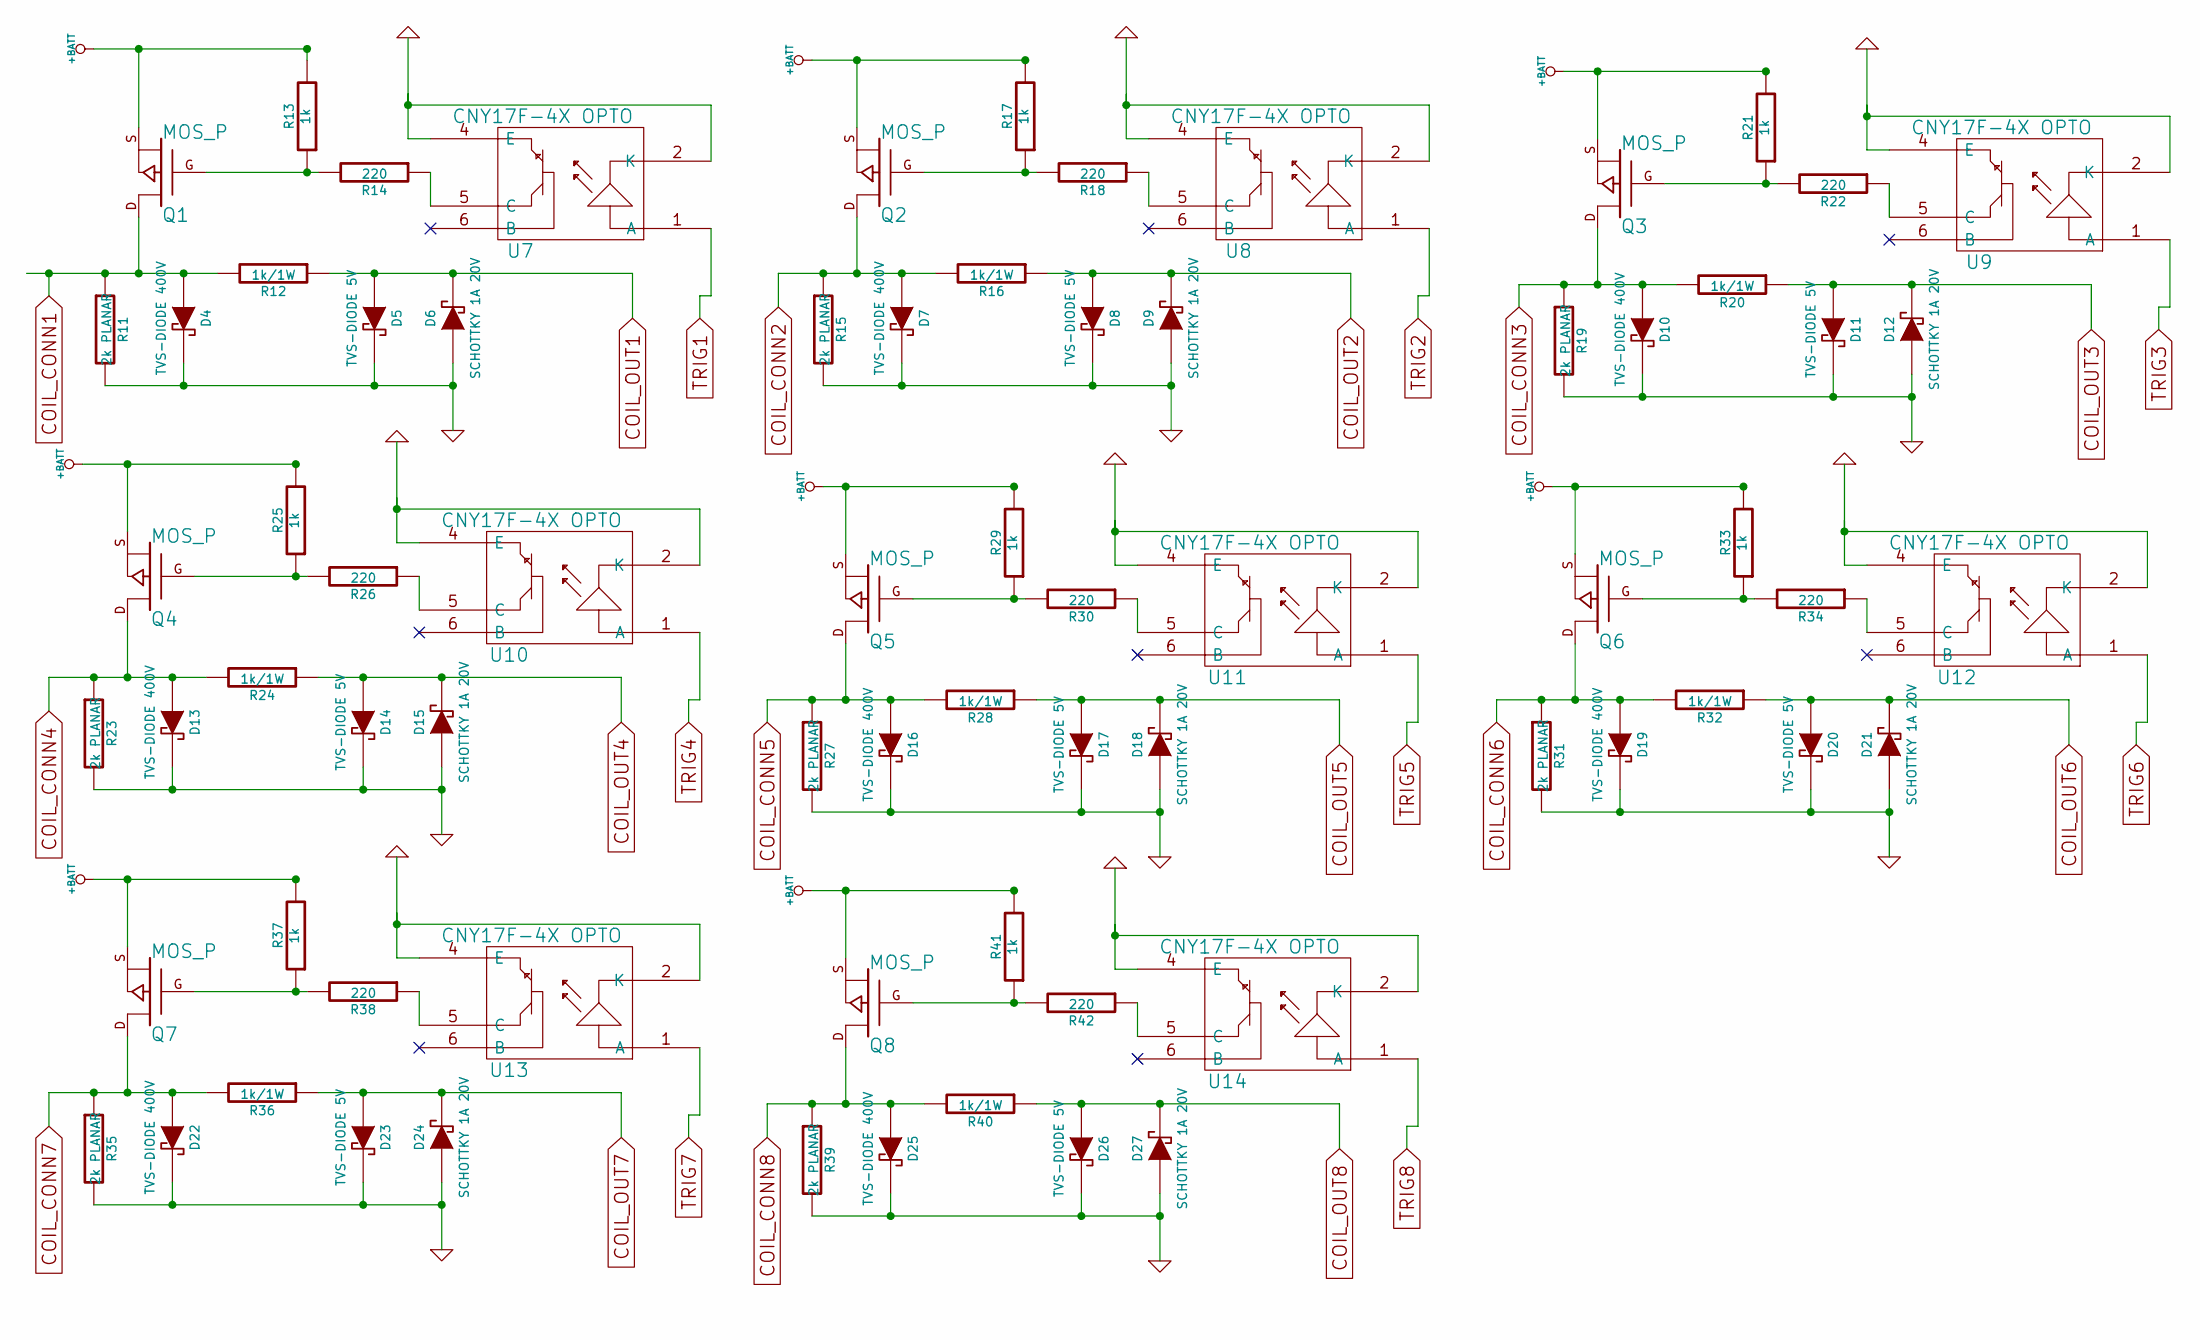
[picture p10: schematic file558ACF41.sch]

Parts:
D4, D7, D10, D13, D16, D19, D22, D25: TVS-DIODE 400V; DO-214AC_Handsoldering
D5, D8, D11, D14, D17, D20, D23, D26: TVS-DIODE 5V; Diode-DO-214AB_Handsoldering
D6, D9, D12, D15, D18, D21, D24, D27: SCHOTTKY 1A 20V; DO-214AC_Handsoldering
Q1, Q2, Q3, Q4, Q5, Q6, Q7, Q8: MOS_P; TO-252-3
R11, R15, R19, R23, R27, R31, R35, R39: 2k PLANAR; R_2512_HandSoldering
R12, R16, R20, R24, R28, R32, R36, R40: 1k/1W; R_2512_HandSoldering
R13, R17, R21, R25, R29, R33, R37, R41: 1k; R_1206_HandSoldering
R14, R18, R22, R26, R30, R34, R38, R42: 220; R_1206_HandSoldering
U7, U8, U9, U10, U11, U12, U13, U14: CNY17F-4X OPTO; SMDIP-6

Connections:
+BATT: Q1.S, Q2.S, Q3.S, Q4.S, Q5.S, Q6.S, Q7.S, Q8.S, R13.2, R17.2, R21.2, R25.2, R29.2, R33.2, R37.2, R41.2; also elsewhere on the board
COIL_CONN1: D4.1 (A), Q1.D, R11.1, R12.2; also elsewhere on the board
COIL_CONN2: D7.1 (A), Q2.D, R15.1, R16.2; also elsewhere on the board
COIL_CONN3: D10.1 (A), Q3.D, R19.1, R20.2; also elsewhere on the board
COIL_CONN4: D13.1 (A), Q4.D, R23.1, R24.2; also elsewhere on the board
COIL_CONN5: D16.1 (A), Q5.D, R27.1, R28.2; also elsewhere on the board
COIL_CONN6: D19.1 (A), Q6.D, R31.1, R32.2; also elsewhere on the board
COIL_CONN7: D22.1 (A), Q7.D, R35.1, R36.2; also elsewhere on the board
COIL_CONN8: D25.1 (A), Q8.D, R39.1, R40.2; also elsewhere on the board
COIL_OUT1: D5.1 (A), D6.2 (K), R12.1; also elsewhere on the board
COIL_OUT2: D8.1 (A), D9.2 (K), R16.1; also elsewhere on the board
COIL_OUT3: D11.1 (A), D12.2 (K), R20.1; also elsewhere on the board
COIL_OUT4: D14.1 (A), D15.2 (K), R24.1; also elsewhere on the board
COIL_OUT5: D17.1 (A), D18.2 (K), R28.1; also elsewhere on the board
COIL_OUT6: D20.1 (A), D21.2 (K), R32.1; also elsewhere on the board
COIL_OUT7: D23.1 (A), D24.2 (K), R36.1; also elsewhere on the board
COIL_OUT8: D26.1 (A), D27.2 (K), R40.1; also elsewhere on the board
GND: D4.2 (K), D5.2 (K), D6.1 (A), D7.2 (K), D8.2 (K), D9.1 (A), D10.2 (K), D11.2 (K), D12.1 (A), D13.2 (K), D14.2 (K), D15.1 (A), D16.2 (K), D17.2 (K), D18.1 (A), D19.2 (K), D20.2 (K), D21.1 (A), D22.2 (K), D23.2 (K), D24.1 (A), D25.2 (K), D26.2 (K), D27.1 (A), R11.2, R15.2, R19.2, R23.2, R27.2, R31.2, R35.2, R39.2, U7.2 (K), U7.4 (E), U8.2 (K), U8.4 (E), U9.2 (K), U9.4 (E), U10.2 (K), U10.4 (E), U11.2 (K), U11.4 (E), U12.2 (K), U12.4 (E), U13.2 (K), U13.4 (E), U14.2 (K), U14.4 (E); also elsewhere on the board
unnamed: Q1.G, R13.1, R14.2
unnamed: Q2.G, R17.1, R18.2
unnamed: Q3.G, R21.1, R22.2
unnamed: Q4.G, R25.1, R26.2
unnamed: Q5.G, R29.1, R30.2
unnamed: Q6.G, R33.1, R34.2
unnamed: Q7.G, R37.1, R38.2
unnamed: Q8.G, R41.1, R42.2
unnamed: R14.1, U7.5 (C)
unnamed: R18.1, U8.5 (C)
unnamed: R22.1, U9.5 (C)
unnamed: R26.1, U10.5 (C)
unnamed: R30.1, U11.5 (C)
unnamed: R34.1, U12.5 (C)
unnamed: R38.1, U13.5 (C)
unnamed: R42.1, U14.5 (C)
TRIG1: U7.1 (A); also elsewhere on the board
TRIG2: U8.1 (A); also elsewhere on the board
TRIG3: U9.1 (A); also elsewhere on the board
TRIG4: U10.1 (A); also elsewhere on the board
TRIG5: U11.1 (A); also elsewhere on the board
TRIG6: U12.1 (A); also elsewhere on the board
TRIG7: U13.1 (A); also elsewhere on the board
TRIG8: U14.1 (A); also elsewhere on the board

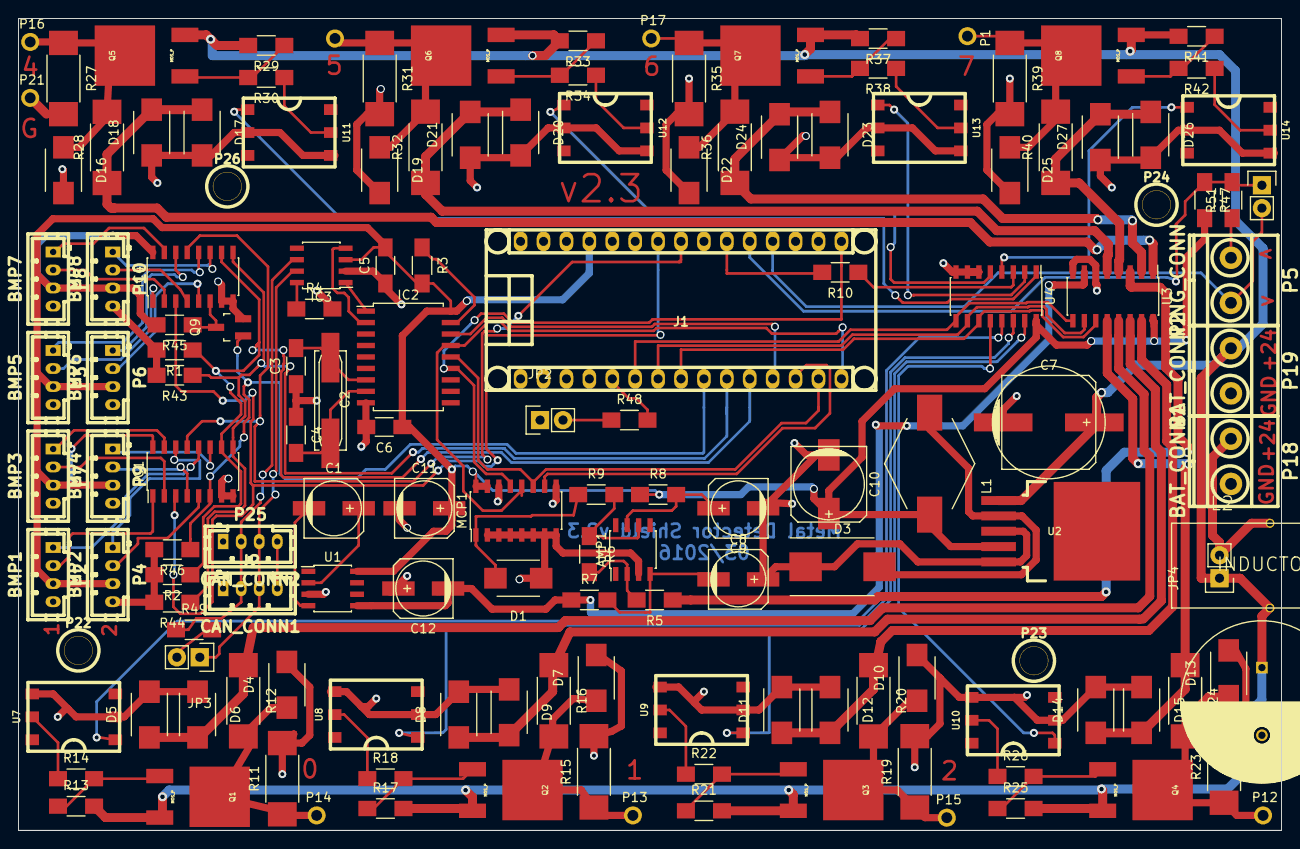
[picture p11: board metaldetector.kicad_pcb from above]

Board: 2 copper layers, 140.0 x 90.0 mm, 149 parts (1 on the bottom side), 101 nets.

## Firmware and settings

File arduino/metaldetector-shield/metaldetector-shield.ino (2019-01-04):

/**
* Copyright 2018, Simon Harst
* This file is part of the Metaldetector project.
* 
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
* You should have received a copy of the GNU Lesser General Public License
* along with Metaldetector.  If not, see <http://www.gnu.org/licenses/>.
*/
#include <SPI.h>
#include <mcp_can.h>
#include <PressureLib.h>
#include "board_v23.h"
#include <CoilLib.h>

#define TX_CAN_ID                 61
#define RX_CAN_ID                 62

// Toggle all debug output on the serial port
#define DEBUG                     true

#define COMM_TIMEOUT              10000

// Output raw ADC values of one coil, -1 to switch off
#define DEBUG_RAW_ADC_COIL        -1
#define DEBUG_RAW_PRESSURE        -1

// Define a switchable debug print function
#ifdef DEBUG
#define DEBUG_PRINTLN(x) Serial.println(x)
#define DEBUG_PRINT(x) Serial.print(x)
#else
#define DEBUG_PRINTLN(x)
#define DEBUG_PRINT(x)
#endif

bool bumpers[8];
byte comm_in_state;
bool comm_out_state = false;

unsigned long start_waiting = 0;
unsigned long last_heartbeat = 0;

unsigned char tx_can_msg[5];
INT8U rx_len = 0;
unsigned char rx_can_msg[5];
bool coils_enabled;
unsigned int coil_value;
long raw_pressure = -1;

byte is_master = 2;  // 0: NO master, 1: IS master, 2: read out hardware switch

Pressure pres = Pressure(pres_mux1, pres_mux2, pres_mux3);
Coil coils = Coil(coil_select1, coil_select2, coil_select3, coil_adc_cs,
    coil_trigger);
MCP_CAN CAN0(can_cs);


bool chain_interrupt_received() {
  if (start_waiting == 0)
    start_waiting = millis();

  byte in = digitalRead(comm_in);
  if (in == comm_in_state) {
    if (is_master && ((millis() - start_waiting) > COMM_TIMEOUT)) {
      DEBUG_PRINTLN("Connection timeout!");
      start_waiting = 0;
      return true;
    } else {
      return false;
    }
  } else {
    comm_in_state = in;
    start_waiting = 0;
    return true;
  }
}

void toggle_out_state() {
  comm_out_state = !comm_out_state;
  digitalWrite(comm_out, comm_out_state);
}


/* Call this function periodically and it will emit a heartbeat message
 * at most every HEARTBEAT_EVERY milliseconds.
 * The heartbeat message is 3 byte long and consists of
 * BYTE #     DESCRIPTION
 * 0          HEARTBEAT_REGISTER
 * 1          number of pressure sensors attached
 * 2          [0 or 1], whether coils are enabled
 */
void send_heartbeat() {
  if ((millis() - last_heartbeat) > HEARTBEAT_EVERY) {

    unsigned char heartbeat_msg[3];
    heartbeat_msg[0] = HEARTBEAT_REGISTER;
    heartbeat_msg[1] = pres.get_available_sensors();
    heartbeat_msg[2] = coils_enabled;
    byte ret = CAN0.sendMsgBuf(TX_CAN_ID, 1, 3, heartbeat_msg);

    if (ret == CAN_OK) {
      DEBUG_PRINTLN("HEARTBEAT msg sent.");
    }
    last_heartbeat = millis();
  }
}

void setup() {
  // Setup chaining pins
  pinMode(comm_in, INPUT_PULLUP);
  pinMode(comm_out, OUTPUT);
  pinMode(master_pin, INPUT_PULLUP);
  digitalWrite(comm_out, comm_out_state);
  delay(2); // Give pin some ms to settle
  comm_in_state = digitalRead(comm_in);

  if (is_master == 2)
    is_master = !digitalRead(master_pin);

  Serial.begin(115200);
  pinMode(LEDPin, OUTPUT);
  digitalWrite(LEDPin, LOW);

  // Setup CAN
  CAN0.begin(CAN_500KBPS);

  // Setup pressure sensors
  pres.setup();
  for (int i = 0; i < 8; i++) {
    DEBUG_PRINT("Trying to detect sensor ");
    DEBUG_PRINTLN(i);
    if (pres.detect_sensor(i)) {
      DEBUG_PRINTLN("SUCCESS!");
    }
  }
  byte amount = pres.get_sensor_amount();
  DEBUG_PRINT("Found ");
  DEBUG_PRINT(amount);
  DEBUG_PRINTLN(" sensors.");

  coils_enabled = true;

  // Setup coils
  coils.setup();

  DEBUG_PRINT("Is this board is configured as master: ");
  DEBUG_PRINTLN(is_master);

  // Wait for master to finish first measurement
  if (!is_master) {
    while (!chain_interrupt_received())
      delay(1);
    DEBUG_PRINTLN("Received very first interrupt as slave.");
  }

  DEBUG_PRINTLN("Setup done!");
}

// Debug function to print the individual ADC values of the last measurements
void print_adc() {
  DEBUG_PRINT("# ");
  for (int i = 0; i < 40; i++) {
    unsigned int adc_val = coils.get_adc(i);
    DEBUG_PRINT(adc_val);
    if (i < 39) {
      DEBUG_PRINT(",");
    }
  }
  DEBUG_PRINTLN("!");
}

// Send a message about the coil values on the bus
void send_value(int value_register, char identifier, int value) {
    unsigned char message[4];
    message[0] = value_register;
    message[1] = identifier;
    message[2] = value >> 8;
    message[3] = value & 0xFF;

    byte ret = CAN0.sendMsgBuf(TX_CAN_ID, 1, 4, message);
    if (ret == CAN_OK) {
      // DEBUG_PRINTLN("COIL msg sent.");
    }
}

// Send a message on the can bus that encodes the given values
void can_response_2_uint16(int index, int val1, int val2) {
  tx_can_msg[0] = index;
  tx_can_msg[1] = highByte(val1);
  tx_can_msg[2] = lowByte(val1);
  tx_can_msg[3] = highByte(val2);
  tx_can_msg[4] = lowByte(val2);
  byte ret = CAN0.sendMsgBuf(TX_CAN_ID, 1, 5, tx_can_msg);
  if (ret == CAN_OK) {
    // DEBUG_PRINTLN("CAN msg sent.");
  }
  delay(2);
}

void handle_incoming_messages() {
  if (CAN_MSGAVAIL == CAN0.checkReceive()) {
    CAN0.readMsgBuf(&rx_len, rx_can_msg);
    INT32U canId = CAN0.getCanId();

    if (canId == RX_CAN_ID)
      handle_request();
  }
}

// Parse the last message that came in.
void handle_request() {
  INT8U reg = rx_can_msg[0];
  bool is_write = ((reg & 0b10000000) > 0);
  reg &= 0b1111111;

  unsigned char data[3];
  unsigned char flash_data[32];

  if (is_write) {
    if (reg == ENABLE_COILS_REGISTER) {
      DEBUG_PRINT("Received request to switch coils to: ");
      DEBUG_PRINTLN(rx_can_msg[1]);
      coils_enabled = (rx_can_msg[1] & 1) == 1;
    }
  } else {
    DEBUG_PRINT("Received read request for register ");
    DEBUG_PRINTLN(reg);
  }
}


/* 1) If coils are enabled, check them and write the data to the bus
 * 2) Check if there have been transitions in the bumper pressure sensors
 *    If yes, send another message on the bus
 * 3) Send a heartbeat message
 */
void loop() {
  if (coils_enabled) {
    // If raw ADC samples are requested, trigger that coil once and read
    // out the samples.
    if (DEBUG_RAW_ADC_COIL > -1) {
      coils.read_coil(DEBUG_RAW_ADC_COIL);
      DEBUG_PRINT("RAWCOIL");
      for (int i=0; i<ADC_SAMPLES; i++) {
        DEBUG_PRINT(" ");
        DEBUG_PRINT(coils.get_adc(i));
      }
      DEBUG_PRINTLN("");
    }

    coils.check_sensors();
    if (coils.data_ready()) {
      // DEBUG_PRINT("COILS");
      for (int i = 0; i < COIL_AMOUNT; i++) {
        coil_value = coils.get_average(i);
        // DEBUG_PRINT(" ");
        // DEBUG_PRINT(coil_value);
        send_value(COIL_REGISTER, i, coil_value);
      }
      //DEBUG_PRINTLN("");
    }
    toggle_out_state();
  }

  do {
    // Update all of the available sensors
    pres.check_sensors();

    if (DEBUG_RAW_PRESSURE > -1) {
      raw_pressure = pres.get_raw(DEBUG_RAW_PRESSURE, true);
      if (raw_pressure > -1) {
        DEBUG_PRINT("RAWPRESSURE ");
        DEBUG_PRINTLN(raw_pressure);
      }
    }

    // Find out which bumpers have transitioned.
    int trans = pres.get_bumper_transitions();

    if (trans > 0) {
      send_value(PRESSURE_REGISTER, 0, trans);
      DEBUG_PRINTLN("BUMPER");
    }
    delay(1);
    handle_incoming_messages();
    send_heartbeat();

  } while (!chain_interrupt_received());
}

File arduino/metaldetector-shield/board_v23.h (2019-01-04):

#ifndef boarddef23_h
#define boarddef23_h 

// Pressure sensor
#define pres_mux1            8
#define pres_mux2            7
#define pres_mux3            6

// Coil sensor
#define coil_adc_cs          10
#define coil_select1         5
#define coil_select2         4
#define coil_select3         3
#define coil_trigger         A2

// CAN settings
#define can_cs               9
#define PRESSURE_REGISTER    25
#define HEARTBEAT_REGISTER   30
#define COIL_REGISTER        40
#define ENABLE_COILS_REGISTER 8
#define HEARTBEAT_EVERY      10000 // How often to send out heartbeat messages

// Chaining settings
#define comm_in              A1
#define comm_out             A0
#define LEDPin               13
#define master_pin           2


#endif

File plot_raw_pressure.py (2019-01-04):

#!/usr/bin/python
"""
Simple script to read out the serial port for any lines that start with 
'RAWPRESSURE'. It will then plot it continuously.
"""
from PythonLivePlotting import plot
import serial
import time


fig = plot.Figure(10);
lp = plot.LinePlot(fig, 10);
vl = plot.VerticalLines(fig, 10, lw=3);

refresh = time.time()

ser = serial.Serial("/dev/ttyUSB0", 115200, timeout = .1)

while True:
    line = ser.readline()
    if line != "":
        # Uncomment to see what arrives on the port.
        # print line,
        pass
    if line.startswith("RAWPRESSURE"):
        # Add the received values to the currently selected line plot
        lp.add_value(float(line.split()[-1]))
        vl.starty = min(lp.y_vals)
        vl.endy = max(lp.y_vals)
    elif line.startswith("BUMPER"):
        vl.add_value()
    if (time.time() - refresh) > 0.1:
        fig.refresh()
        refresh = time.time()

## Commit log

2018-12-30 First checkin of metaldetector arduino files
2018-12-30 Add a gif of the coil response (raw ADC measurements)
2018-12-31 Add some images and the BOM
    [BOM_metaldetector_shield_v2_3.ods]
2018-12-31 Inserted images.
2018-12-31 Commit kicad files
    [PressureMultiplexers.sch, file558A8F82.sch, file558AA5BE.sch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]
2019-01-04 Proper handling of master switch
2019-01-04 Allow output of raw pressure values
2019-01-04 Add script to plot raw pressure values and bumper transitions
2019-01-04 Add example image of a pressure sensor response

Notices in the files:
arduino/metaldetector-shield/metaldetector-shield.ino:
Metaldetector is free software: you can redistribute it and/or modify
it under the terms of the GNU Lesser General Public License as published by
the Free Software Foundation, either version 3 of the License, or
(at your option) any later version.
